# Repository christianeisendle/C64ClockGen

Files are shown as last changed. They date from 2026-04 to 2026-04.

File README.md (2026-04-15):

# C64 Clock Generator
## Introduction
This is a replacement for the MOS 8701 clock generator IC used in C64 board revisions 250425-01 and later.
It's not a 1:1 replica but the generated clocks follow more strictly the PAL specification.
MOS 8701 is a simple PLL which generates two clocks using a 17.734475 MHz XTAL oscillator. These clocks are:
- Color clock using directly the oscillator frequency of 17.734475 MHz
- Dot clock ("pixel clock") running at 7.8882 MHz

The Dot clock is generated by multiplying the color clock by 4 and divide by 9: 

$`\frac{17.734475MHz * 4}{9} = 7.8882MHz`$

Furthermore, VIC divides the dot clock by 8 (as one character consists of 8 pixel and memory access is character based) which gives the $`\phi0`$ clock of 0.986025MHz which is also the resulting CPU and VIC frequency. This is where C64 violates the PAL standard: One raster line is made of 63 CPU/VIC cycles which gives a duration of

$`\frac{1}{0.986025MHz}*63 = 63.8929us`$

However, PAL defines the horizontal/line frequency as 15.625kHz which is 64us. So C64 is off here by 

$`1-\frac{63.8929us}{64us} = 1.676\%`$

On old CRT screens this isn't really an issue as they make use of the synchronization pulses within the video signal. However, modern LCD screens (which perform internal AD conversion of the video signal) are quite strict on these tolerances and produce screen artifacts in case frequency deviation becomes too big. In particular, Samsung based models need an exact ratio between the color frequency of the video signal and the horizontal/vertical line/screen frequency as defined by PAL. While C64 precisely implements the color frequency of 4.43361875 MHz (which is the 17.734475 MHz color clock divided by 4) the line/screen frequency and with that the overall ratio is off.

## Design
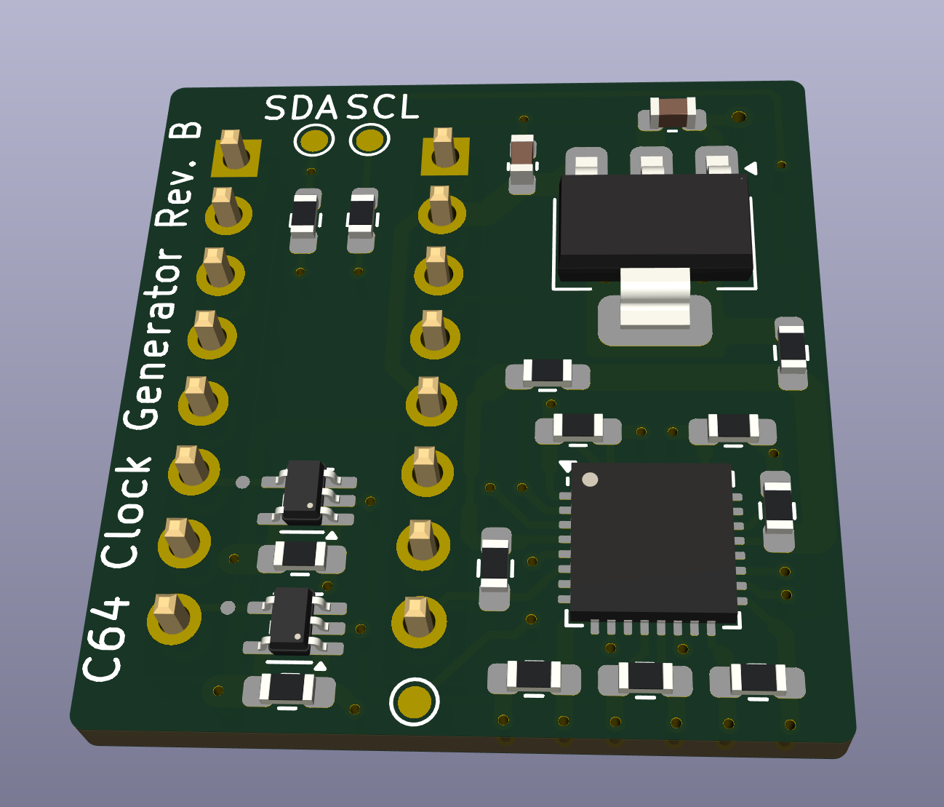
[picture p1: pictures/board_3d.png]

This clock generator uses a the IDT5V49EE902 programable clock generator from Renasas to generate the required clocks. This IC has a built-in EEPROM to store the configuration, i.e. an extra microcontroller is not needed for operation (but required for initial programming). The integrated XTAL oscillator uses the existing 17.734475 MHz XTAL on the C64 board, so only MOS 8701 needs to be replaced. The color clock is directly generated by this oscillator while the dot clock is created using frequency synthesis and the included PLL. The PLL output frequency is configured to 425.25 MHz which is fed into an output divider of ratio 54. The output frequency based on input frequency is defined as:

$`f_{out} = f_{in} * \frac{M}{D} * Q`$

where M and D are the PLL loop dividers and Q is the output divider. With M = 1127, D = 47 and Q = 54 we get the following dot clock for an input frequency of 17.734475 MHz:

$`f_{out} = 17.734475MHz * \frac{1127}{47} * 54 = 7.875MHz`$

This results in a line frequency of

$`f_{line} =  \frac{7.875MHz}{8} / 63 = 15.625kHz`$

## Programming the IDT5V49EE902
The python script in `pll/prog.py` contains the programming sequence for the IDT5V49EE902 using I2C. The script can be executed on a Raspberry Pi Pico running MicroPython (https://www.raspberrypi.com/documentation/microcontrollers/micropython.html). Porting it to another MicroController or a USB to I2C bridge should be easily possible. The C64 Clock Generator Board has two I2C testpads exposed with on board pull-up resistors.

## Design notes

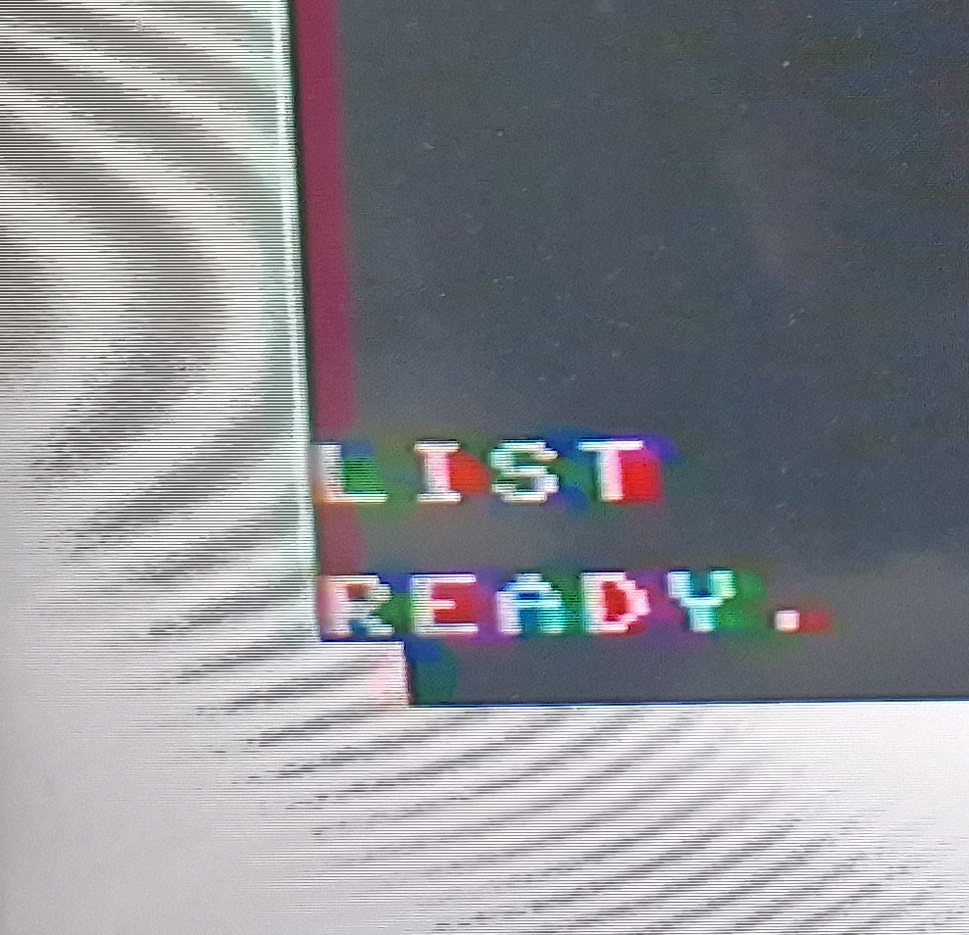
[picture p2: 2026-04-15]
pictures/color_artifacts.png

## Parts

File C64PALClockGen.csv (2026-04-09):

Reference | Value | Footprint | Datasheet | Qty | DNP | Exclude from BOM | Exclude from Board
C1 | 1u | Capacitor_SMD:C_0603_1608Metric | ~ | 1
C2 | 4u7 | Capacitor_SMD:C_0603_1608Metric | ~ | 1
C3 | 100n | Resistor_SMD:R_0402_1005Metric | ~ | 1
J1,J2 | Conn_01x08_Pin | Connector_PinHeader_2.54mm:PinHeader_1x08_P2.54mm_Vertical | ~ | 2
J3 | CLKIN | Connector_PinHeader_1.00mm:PinHeader_1x02_P1.00mm_Vertical | ~ | 1
J4 | I2C | Connector_PinHeader_1.00mm:PinHeader_1x03_P1.00mm_Vertical | ~ | 1
R1 | 5R | Resistor_SMD:R_0402_1005Metric | ~ | 1
R2,R3 | 4k7 | Resistor_SMD:R_0402_1005Metric | ~ | 2
U1 | SN74LV4T125 | Package_DFN_QFN:Texas_S-PVQFN-N14 | https://www.ti.com/lit/ds/symlink/sn74lv4t125.pdf | 1
U2 | LDL1117S33 | Package_TO_SOT_SMD:SOT-223-3_TabPin2 | http://www.ti.com/lit/ds/symlink/lm1117.pdf | 1
Y1 | 5V49EE902 | Package_DFN_QFN:QFN-32-1EP_5x5mm_P0.5mm_EP3.3x3.3mm | https://www.mouser.at/datasheet/2/698/REN_5V49EE902_DST_20151214-1995896.pdf | 1

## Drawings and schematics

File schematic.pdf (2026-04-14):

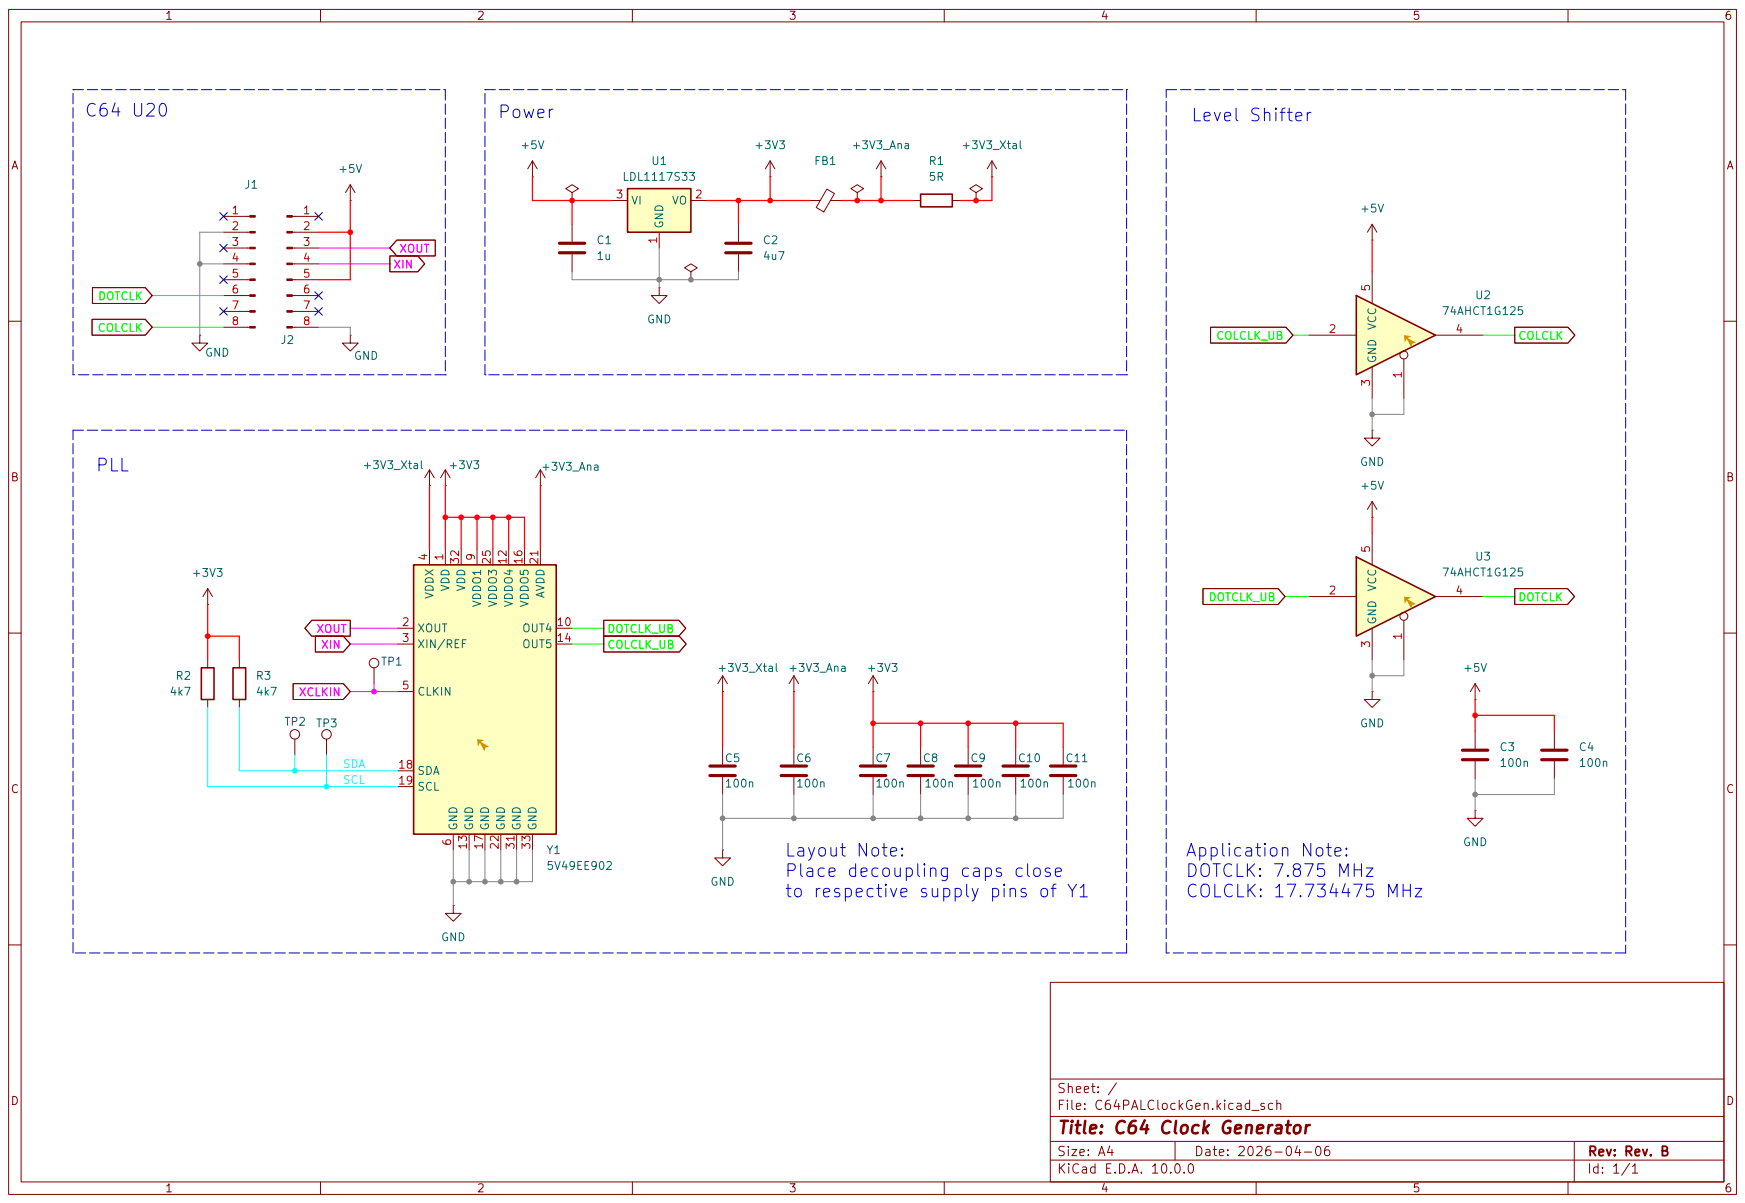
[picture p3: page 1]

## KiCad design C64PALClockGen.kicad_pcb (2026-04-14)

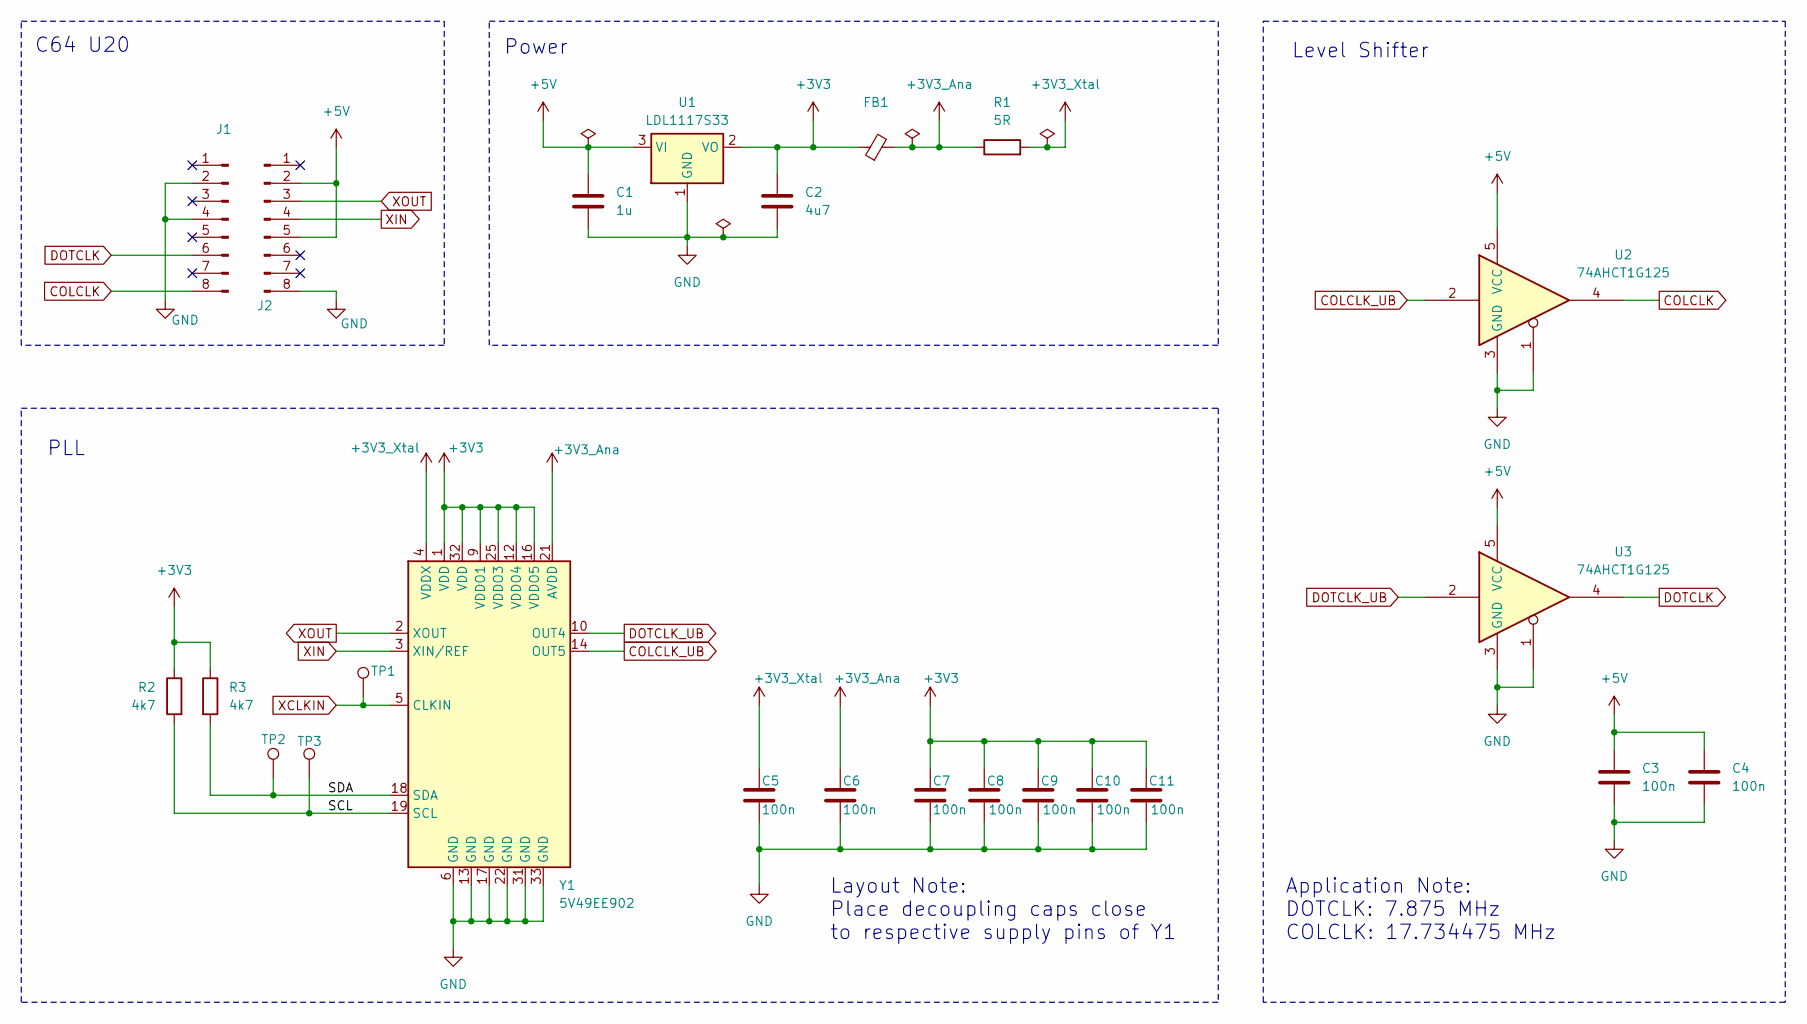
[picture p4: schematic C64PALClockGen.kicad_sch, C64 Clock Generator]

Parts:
C1: 1u; C_0603_1608Metric
C2: 4u7; C_0603_1608Metric
C3, C4, C5, C6, C7, C8, C9, C10, C11: 100n; R_0603_1608Metric_Pad0.98x0.95mm_HandSolder
FB1: FerriteBead_Small; R_0603_1608Metric_Pad0.98x0.95mm_HandSolder
J1, J2: Conn_01x08_Pin; PinHeader_1x08_P2.54mm_Vertical
R1: 5R; R_0603_1608Metric_Pad0.98x0.95mm_HandSolder
R2, R3: 4k7; R_0603_1608Metric_Pad0.98x0.95mm_HandSolder
TP1: CLKIN; TestPoint_Pad_D1.0mm
TP2: SDA; TestPoint_Pad_D1.0mm
TP3: SCL; TestPoint_Pad_D1.0mm
U1: LDL1117S33; SOT-223-3_TabPin2
U2, U3: 74AHCT1G125; SOT-353_SC-70-5
Y1: 5V49EE902; QFN-32-1EP_5x5mm_P0.5mm_EP3.3x3.3mm

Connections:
+3V3: C2.1, C7.1, C8.1, C9.1, C10.1, C11.1, FB1.1, R2.1, R3.1, U1.2 (VO), Y1.1 (VDD), Y1.9 (VDDO1), Y1.12 (VDDO4), Y1.16 (VDDO5), Y1.25 (VDDO3), Y1.32 (VDD)
+3V3_Ana: C6.1, FB1.2, R1.1, Y1.21 (AVDD)
+3V3_Xtal: C5.1, R1.2, Y1.4 (VDDX)
+5V: C1.1, C3.1, C4.1, J2.2, J2.5, U1.3 (VI), U2.5 (VCC), U3.5 (VCC)
/SCL: R2.2, TP3.1 (1_1), Y1.19 (SCL)
/SDA: R3.2, TP2.1 (1_1), Y1.18 (SDA)
COLCLK: J1.8, U2.4
COLCLK_UB: U2.2, Y1.14 (OUT5)
DOTCLK: J1.6, U3.4
DOTCLK_UB: U3.2, Y1.10 (OUT4)
GND: C1.2, C2.2, C3.2, C4.2, C5.2, C6.2, C7.2, C8.2, C9.2, C10.2, C11.2, J1.2, J1.4, J2.8, U1.1 (GND), U2.1, U2.3 (GND), U3.1, U3.3 (GND), Y1.6 (GND), Y1.13 (GND), Y1.17 (GND), Y1.22 (GND), Y1.31 (GND), Y1.33 (GND)
XCLKIN: TP1.1 (1_1), Y1.5 (CLKIN)
XIN: J2.4, Y1.3 (XIN/REF)
XOUT: J2.3, Y1.2 (XOUT)

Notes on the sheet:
C64 U20
Level Shifter
Layout Note: Place decoupling caps close to respective supply pins of Y1
Power
PLL
Application Note: DOTCLK: 7.875 MHz COLCLK: 17.734475 MHz

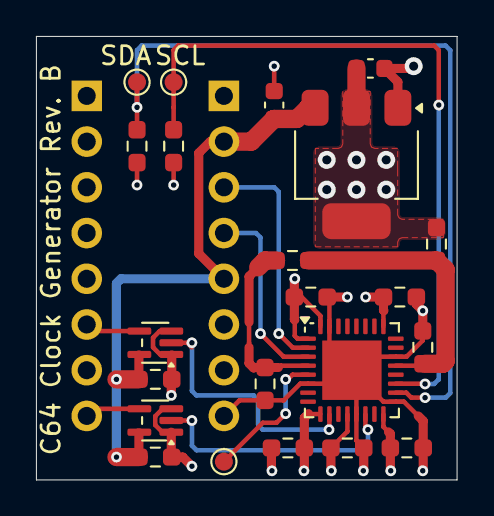
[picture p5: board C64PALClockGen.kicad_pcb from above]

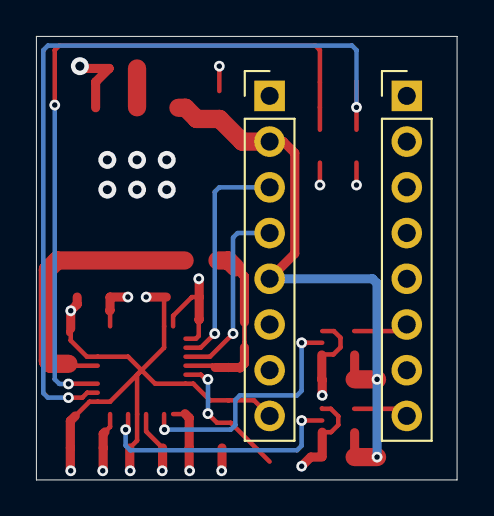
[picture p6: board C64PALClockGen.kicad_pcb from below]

Board: 4 copper layers, 23.4 x 24.6 mm, 24 parts (2 on the bottom side), 14 nets.

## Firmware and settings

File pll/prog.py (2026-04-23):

# IDT5V49EE902 configuration and programming script for MicroPython on Raspberry Pi Pico.
import machine

addr=0b1101010
i2c=machine.I2C()

def read_reg(regaddr):
    i2c.writeto(addr, bytearray([0, regaddr]))
    return i2c.readfrom(addr, 2)[1]

def write_reg(regaddr, val):
    i2c.writeto(addr, bytearray([0, regaddr, val]))

def mod_reg(regaddr, mask, val):
    regval = read_reg(regaddr)
    regval = (regval & ~mask) | (val & mask)
    write_reg(regaddr, regval)

def set_reg_bit(regaddr, bit):
    mod_reg(regaddr, 1<<bit, 1<<bit)

def clear_reg_bit(regaddr, bit):
    mod_reg(regaddr, 1<<bit, 0)

def prog_save():
    i2c.writeto(addr, bytearray([1]))

# xtal trim 12 (3.5pF+31*0.125pF)
mod_reg(0x7, 0x1f, 0x1f)
# use sw ctrl cfg
set_reg_bit(0x0, 0)
# select config 0
mod_reg(0x1, 0x7, 0x0)

# Input clock configuration:
# Use XTAL (bit[0] = 0)
# switch mode manual (bit[2:1] = 0)
mod_reg(0xc0, 0x3, 0)

# Configure color clock output (17.734475 MHz) (output 5)
# set src mux (bit[4:2]) for output 5 to input/reference clock (value 2)
mod_reg(0xcc, 3 << 2, 2 << 2)
# bypass output divider for output 5
write_reg(0xa0, 0xff)


### pll config for 7.875MHz
# pll1
# disable PLL
write_reg(0x28, 0x0)
# set loop bandwidth parameter
# rz = 0xf, ip = 1, cz = 1 --> 0x9f
write_reg(0x24, 0x9f)
# fout = fin * M/D
# --> fin = 17.734475MHz. With M=1127 and D=47, fout = 17.734475 * 1127/47 = 425.25MHz.
# M = 1127. Split over two registers, M[7:0] in 0x30, M[10:8] in 0x34.
write_reg(0x30, 0x67)
write_reg(0x34, 0x4)
# D = 47
write_reg(0x28, 47)
# enable output divider for output 4. 
# Needed divider is 54. PLL frequency is 425.25007MHz --> 425.25MHz/54 = 7.875MHz
# Register value: divider = (q+2)*2 --> q = 25
# Additionally, MSB to set to 1 --> 25 + 128 = 153 = 0x99
write_reg(0x9c, 0x99)
# Configure dot clock output (7.875MHz) (output 4)
# select PLL1 as as source for output 4 (value 5). Split over two registers, two MSBs in 0xcc, LSB in 0xc4
set_reg_bit(0xc4, 7)
mod_reg(0xcc, 0x3, 0x2)

# output configuration:
# - Enable LVTTL (bit[1:0] = 0)
# - Lowest slew rate (bit[5:4] = 0)
mod_reg(0x79, 0x33, 0)
mod_reg(0x7a, 0x33, 0)
# enable output 4 and 5
set_reg_bit(0x3, 4)
set_reg_bit(0x3, 5)

# uncomment for programming to eeprom:
#prog_save()

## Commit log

2026-04-09 Finalized v2 dual layer
    [C64PALClockGen.kicad_pcb, C64PALClockGen.kicad_sch]
2026-04-14 C64 Clock Generator Rev.B
    [C64PALClockGen.kicad_pcb, C64PALClockGen.kicad_sch]
2026-04-14 Re-generated schematic.pdf
2026-04-23 Rework programming script
    - Use mod_reg and set/clear bit helpers to avoid accidental overwrite of values
    - Add more documentation
    [prog.py]
